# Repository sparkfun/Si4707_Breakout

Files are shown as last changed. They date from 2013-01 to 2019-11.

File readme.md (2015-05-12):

SparkFun Si4707 Weather Band Radio Receiver
==================================

SparkFun Si4707 Weather Band Radio Breakout  

[*SparkFun Si4707 Weather Band Radio Breakout (WRL-11129)*](https://www.sparkfun.com/products/11129)

The Si4707 IC is the industry's first weather band (WB) radio receiver to include a specific area message encoding (SAME) processor. 

Features:

* Weather band support (162.4–162.55 MHz)
* SAME processor
* 1050 Hz alert tone detection
* Frequency synthesizer with integrated VCO
* WB digital tuning
* Programmable reference clock
* 2.7 to 5.5 V supply voltage

Repository Contents
-------------------
* **/Firmware** - Arduino example sketch
* **/Hardware** - PCB design files (created with version 6.2.0 of Eagle)
* **/Production** - Production panel files (.brd)
* [Wiki](https://github.com/sparkfun/Si4707_Breakout/wiki) - Be sure to check out the [hardware support](https://github.com/sparkfun/Si4707_Breakout/wiki/Si4707-Breakout-Hardware-Support) page for more information on using the Si4707 breakout board.

Documentation
--------------
* **[Hookup Guide](https://learn.sparkfun.com/tutorials/si4707-hookup-guide)** - Basic hookup guide for the sI4707.
* **[SparkFun Fritzing repo](https://github.com/sparkfun/Fritzing_Parts)** - Fritzing diagrams for SparkFun products.
* **[SparkFun 3D Model repo](https://github.com/sparkfun/3D_Models)** - 3D models of SparkFun products. 

License Information
-------------------
This product is _**open source**_! 

The **hardware** is released under [Creative Commons ShareAlike 4.0 International](https://creativecommons.org/licenses/by-sa/4.0/).

The **code** is beerware; if you see me (or any other SparkFun employee) at the local, and you've found our code helpful, please buy us a round!

Please use, reuse, and modify these files as you see fit. Please maintain attribution to SparkFun Electronics and release anything derivative under the same license.

Distributed as-is; no warranty is given.

- Your friends at SparkFun.

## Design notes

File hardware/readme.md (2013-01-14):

# What Are these Files?

The .sch and .brd files hare are Eagle CAD schematic and PCB design files.

These files were created with Eagle 6.2.0, you'll need Eagle 6.0 or later to open them up. There is a free, lite, version of Eagle available from [cadsoftusa.com](cadsoftusa.com).

# Board Features

# License

This product is open source! These Eagle files are released under the Creative Commons Share-Alike Attribution license ([CC BY-SA 3.0](http://creativecommons.org/licenses/by-sa/3.0/us/)).

Please use, reuse, and modify these files as you see fit. Please maintain attribution and release anything derivative under the same license.

- Your friends at SparkFun.

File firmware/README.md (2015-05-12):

SparkFun Si4707 Weather Band Radio Firmware
============================================

* **Si4707_Example_Code_I2C** - Arduino Example sketches

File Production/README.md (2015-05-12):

SparkFun <PRODUCT NAME> Production Files
=========================================

These are the production files SparkFun uses for printing PCBs.

License Information
-------------------
This product is open source! 

The hardware is released under [Creative Commons ShareAlike 4.0 International](https://creativecommons.org/licenses/by-sa/4.0/).

Please use, reuse, and modify these files as you see fit. Please maintain attribution to SparkFun Electronics and release anything derivative under the same license.

Distributed as-is; no warranty is given.

- Your friends at SparkFun.

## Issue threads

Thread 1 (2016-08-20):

No need to wait for data after Wire.requestFrom() and no endTransmission.

Koepel, 2016-08-20:
In the file si4707_system_functions.ino, there is no need for a timeout after the Wire.requestFrom() call. And it should not be followed by a Wire.endTransmission.

When the Wire.requestFrom() function returns, the I2C transaction has completely finished and the received data is in the receive buffer in the Wire library. The Wire.read() only reads data from that buffer.

loricrotser, 2019-11-05:
Verified and Fixed.

Koepel, 2019-11-05:
There is still a timeout after the Wire.requestFrom() in the code. The timeout can be removed.
Explanation: [Common-mistakes#1](https://github.com/Koepel/How-to-use-the-Arduino-Wire-library/wiki/Common-mistakes#1)

When the sensor is not connected (or when there was a bus error), the Wire.available() returns zero. In that case, the timeout will eventually become zero and the data is not read.
However, there is no need for a timeout and a single check is enough to test if the sensor is not connected (or if there was a bus error):
```
void i2cReadBytes(byte number_bytes, byte * data_in)
{
  Wire.requestFrom((byte) SI4707_ADDRESS, number_bytes);
  if(Wire.available() == number_bytes)
  {
    while(number_bytes--)
    {
      *data_in++ = Wire.read();
    }
  }
}
```

Closed 2019-11-05.

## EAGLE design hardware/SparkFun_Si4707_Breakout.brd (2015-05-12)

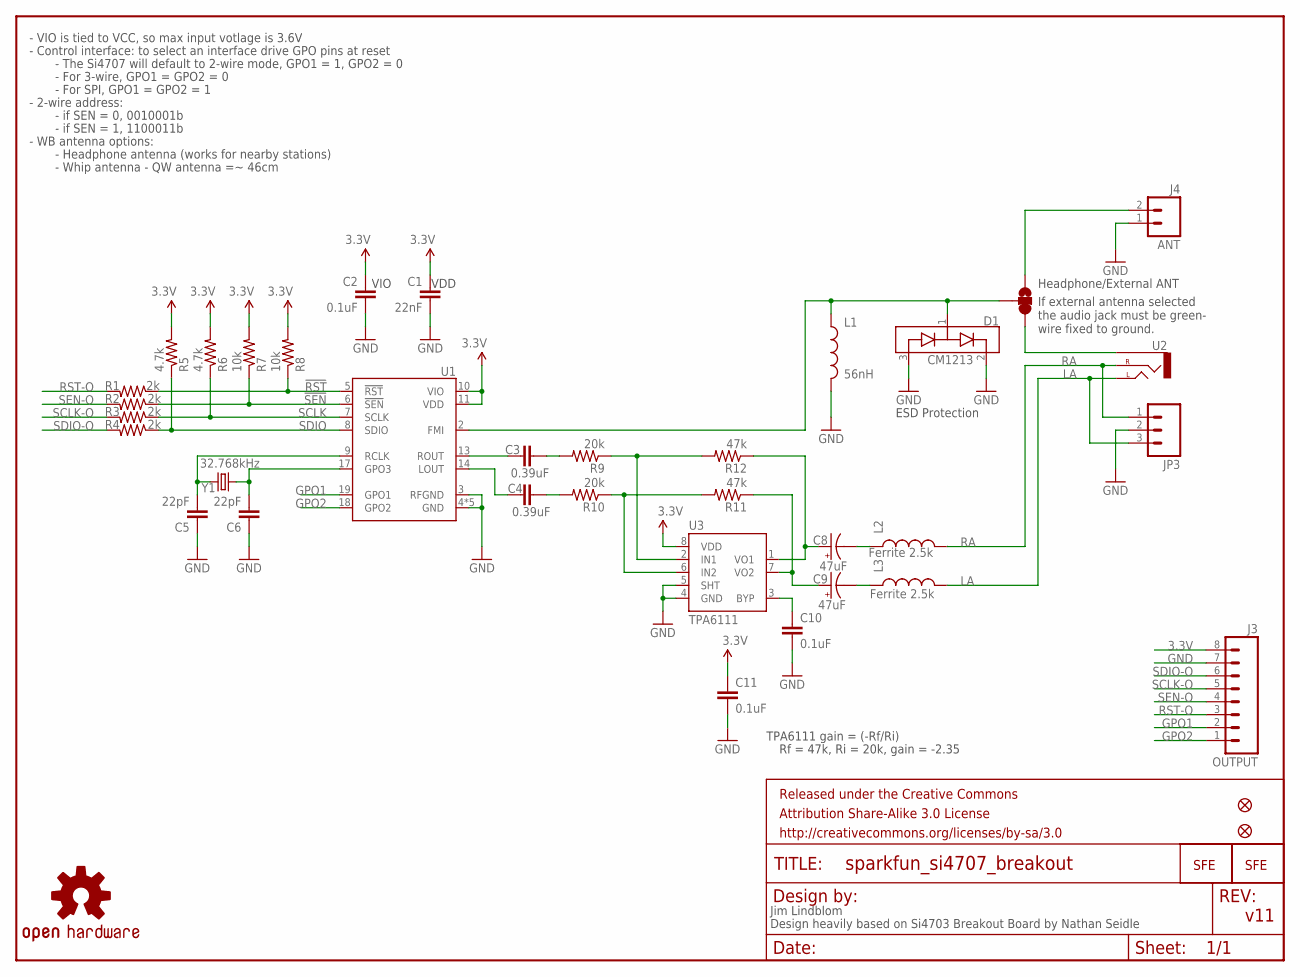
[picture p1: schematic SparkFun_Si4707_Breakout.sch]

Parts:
C1: 22nF; 0402-CAP
C2, C10, C11: 0.1uF; 0402-CAP
C3, C4: 0.39uF; 0402-CAP
C5, C6: 22pF; 0402-CAP
C8, C9: 47uF; EIA3528
D1: CM1213; SOT23-3
FRAME1: FRAME-LETTER; CREATIVE_COMMONS
J3: OUTPUT; 1X08
J4: ANT; 1X02
JP1: LOGO-SFENEW; SFE-NEW-WEBLOGO
JP2: LOGO-SFESK; SFE-LOGO-FLAME
JP3: M03PTH; 1X03
JP4, JP5: FIDUCIALUFIDUCIAL; MICRO-FIDUCIAL
L1: 56nH; 0603
L2, L3: Ferrite 2.5k; C0402
R1, R2, R3, R4: 2k; 0402-RES
R5, R6: 4.7k; 0402-RES
R7, R8: 10k; 0402-RES
R9, R10: 20k; 0402-RES
R11, R12: 47k; 0402-RES
SJ2: SOLDERJUMPER_2WAYS; SJ_3
U1: SI4707; SI470X
U2: AUDIO-JACKSMD2; AUDIO-JACK-3.5MM-SMD
U3: TPA6111; SPARKFUN_SO08
U$2: OSHW-LOGOS; OSHW-LOGO-S
Y1: 32.768kHz; CRYSTAL-32KHZ-SMD

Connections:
3.3V: C1.1, C2.1, C11.1, J3.8, R5.2, R6.2, R7.2, R8.2, U1.10 (VIO), U1.11 (VDD), U3.8 (VDD)
!RST: R1.1, R8.1, U1.5 (!RST)
!SEN: R2.1, R7.1, U1.6 (!SEN)
GND: C1.2, C2.2, C5.1, C6.1, C10.2, C11.2, D1.2 (VP), D1.3 (VN), J3.7, J4.1, JP3.2, L1.2, U1.3 (RFGND), U1.4 (GND), U1.12 (GND), U1.15 (GND), U1.16 (GND), U1.21 (GND), U3.4 (GND), U3.5 (SHT)
GPO1: J3.2, U1.19 (GPO1)
GPO2: J3.1, U1.18 (GPO2)
J1: D1.1 (CH1), L1.1, SJ2.2, U1.2 (FMI)
LA: JP3.3, L3.2, U2.TIP (LEFT)
LOUT: C4.1, U1.14 (LOUT)
unnamed: C3.2, R9.2
unnamed: C4.2, R10.2
unnamed: C6.2, U1.17 (GPO3), Y1.X1 (1)
unnamed: SJ2.1, U2.SLEEVE
unnamed: J4.2, SJ2.3
unnamed: R9.1, R12.2, U3.2 (IN1)
unnamed: R10.1, R11.2, U3.6 (IN2)
unnamed: C10.1, U3.3 (BYP)
unnamed: C8.C (-), L2.1
unnamed: C9.C (-), L3.1
unnamed: C8.A (+), R12.1, U3.1 (VO1)
unnamed: C9.A (+), R11.1, U3.7 (VO2)
RA: JP3.1, L2.2, U2.RING (RIGHT)
RCLK: C5.2, U1.9 (RCLK), Y1.X2 (2)
ROUT: C3.1, U1.13 (ROUT)
RST-O: J3.3, R1.2
SCLK: R3.1, R6.1, U1.7 (SCLK)
SCLK-O: J3.5, R3.2
SDIO: R4.1, R5.1, U1.8 (SDIO)
SDIO-O: J3.6, R4.2
SEN-O: J3.4, R2.2

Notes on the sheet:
Jim Lindblom
VDD
VIO
Design heavily based on Si4703 Breakout Board by Nathan Seidle
- VIO is tied to VCC, so max input votlage is 3.6V
- Control interface: to select an interface drive GPO pins at reset
- The Si4707 will default to 2-wire mode, GPO1 = 1, GPO2 = 0
- For 3-wire, GPO1 = GPO2 = 0
- For SPI, GPO1 = GPO2 = 1
- 2-wire address:
- if SEN = 0, 0010001b
- if SEN = 1, 1100011b
- WB antenna options:
- Headphone antenna (works for nearby stations)
- Whip antenna - QW antenna =~ 46cm
ESD Protection
Headphone/External ANT
TPA6111 gain = (-Rf/Ri)
Rf = 47k, Ri = 20k, gain = -2.35
If external antenna selected the audio jack must be green- wire fixed to ground.
v11

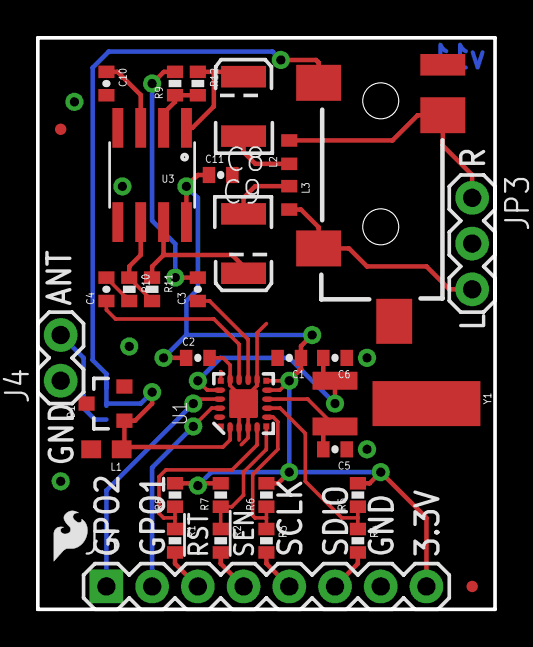
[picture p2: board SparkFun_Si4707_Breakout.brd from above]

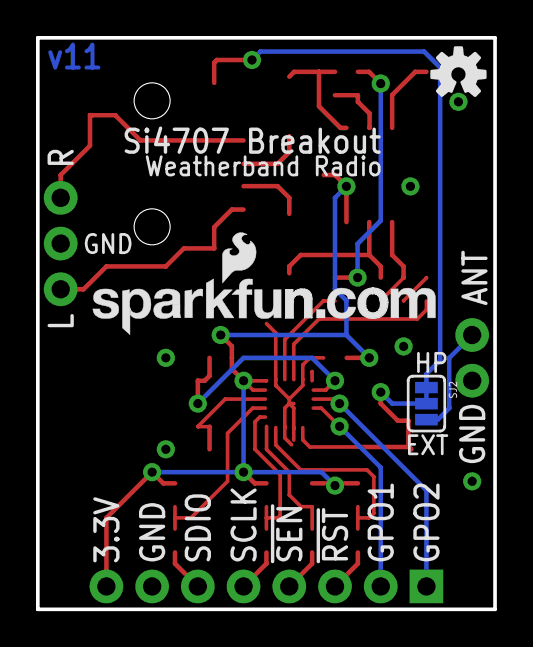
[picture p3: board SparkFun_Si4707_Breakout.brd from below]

Board: 2 copper layers, 25.4 x 31.8 mm, 40 parts (3 on the bottom side), 30 nets.

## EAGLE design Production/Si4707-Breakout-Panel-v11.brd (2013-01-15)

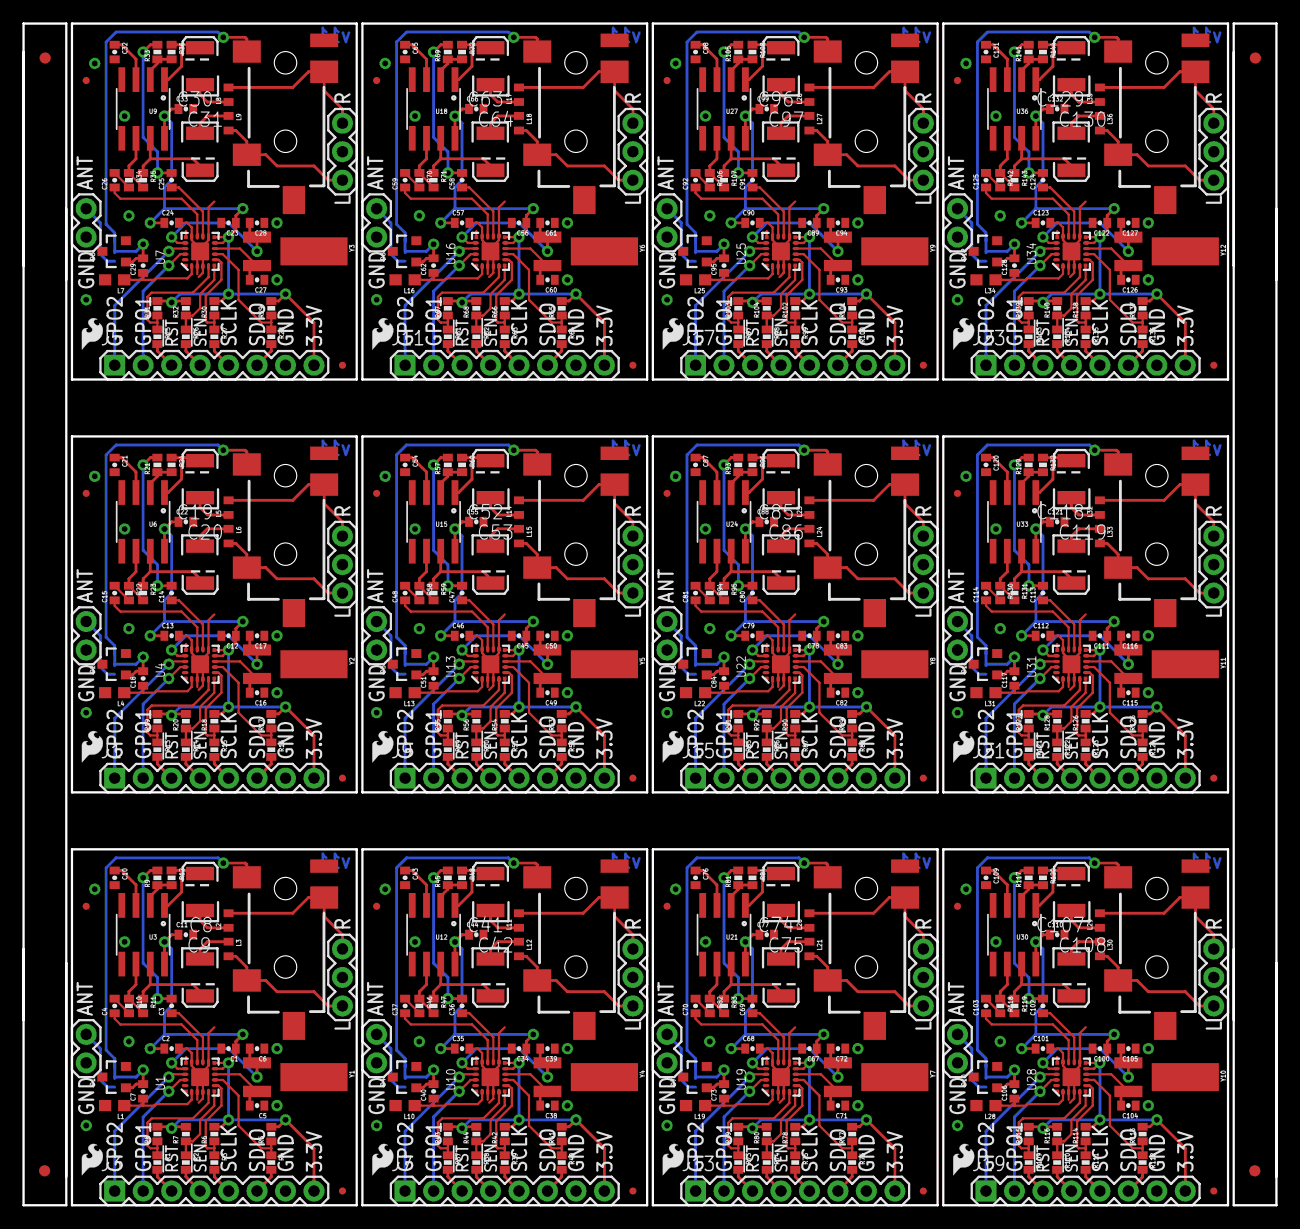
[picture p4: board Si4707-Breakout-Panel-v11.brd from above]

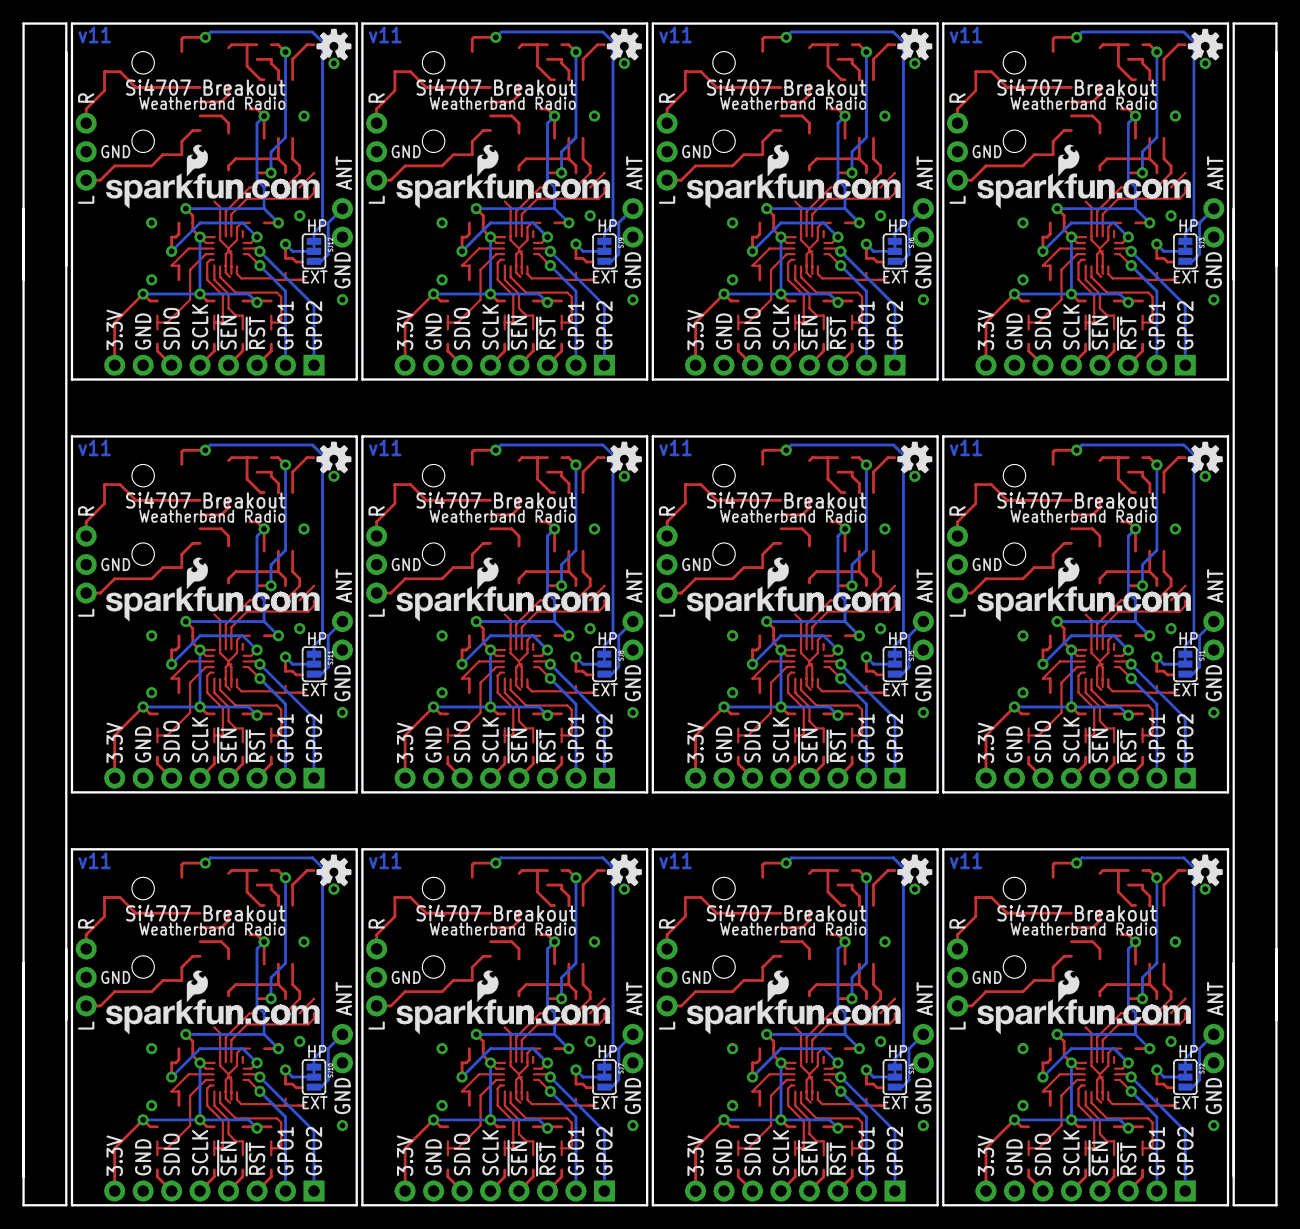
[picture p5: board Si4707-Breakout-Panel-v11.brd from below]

Board: 2 copper layers, 111.8 x 105.4 mm, 484 parts (36 on the bottom side), 372 nets.

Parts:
C1, C12, C23, C34, C45, C56, C67, C78, C89, C100, C111, C122: 22nF; 0402-CAP
C2, C10, C11, C13, C21, C22, C24, C32, C33, C35, C43, C44, C46, C54, C55, C57, C65, C66, C68, C76, C77, C79, C87, C88, C90, C98, C99, C101, C109, C110, C112, C120, C121, C123, C131, C132: 0.1uF; 0402-CAP
C3, C4, C14, C15, C25, C26, C36, C37, C47, C48, C58, C59, C69, C70, C80, C81, C91, C92, C102, C103, C113, C114, C124, C125: 0.39uF; 0402-CAP
C5, C6, C16, C17, C27, C28, C38, C39, C49, C50, C60, C61, C71, C72, C82, C83, C93, C94, C104, C105, C115, C116, C126, C127: 22pF; 0402-CAP
C7, C18, C29, C40, C51, C62, C73, C84, C95, C106, C117, C128: 1nF; 0402-CAP
C8, C9, C19, C20, C30, C31, C41, C42, C52, C53, C63, C64, C74, C75, C85, C86, C96, C97, C107, C108, C118, C119, C129, C130: 47uF; EIA3528
D1, D2, D3, D4, D5, D6, D7, D8, D9, D10, D11, D12: CM1213; SOT23-3
E$1, E$2, E$3, E$4: FIDUCIAL-1X2
J1, J3, J5, J7, J9, J11, J13, J15, J17, J19, J21, J23: OUTPUT; 1X08
J2, J4, J6, J8, J10, J12, J14, J16, J18, J20, J22, J24: ANT; 1X02
JP1, JP6, JP11, JP16, JP21, JP26, JP31, JP36, JP41, JP46, JP51, JP56: LOGO-SFENEW; SFE-NEW-WEBLOGO
JP2, JP7, JP12, JP17, JP22, JP27, JP32, JP37, JP42, JP47, JP52, JP57: LOGO-SFESK; SFE-LOGO-FLAME
JP3, JP8, JP13, JP18, JP23, JP28, JP33, JP38, JP43, JP48, JP53, JP58: 1X03
JP4, JP5, JP9, JP10, JP14, JP15, JP19, JP20, JP24, JP25, JP29, JP30, JP34, JP35, JP39, JP40, JP44, JP45, JP49, JP50, JP54, JP55, JP59, JP60: FIDUCIALUFIDUCIAL; MICRO-FIDUCIAL
L1, L4, L7, L10, L13, L16, L19, L22, L25, L28, L31, L34: 56nH; 0603
L2, L3, L5, L6, L8, L9, L11, L12, L14, L15, L17, L18, L20, L21, L23, L24, L26, L27, L29, L30, L32, L33, L35, L36: Ferrite 2.5k; C0402
R1, R2, R3, R4, R13, R14, R15, R16, R25, R26, R27, R28, R37, R38, R39, R40, R49, R50, R51, R52, R61, R62, R63, R64, R73, R74, R75, R76, R85, R86, R87, R88, R97, R98, R99, R100, R109, R110, R111, R112, R121, R122, R123, R124, R133, R134, R135, R136: 2k; 0402-RES
R5, R6, R17, R18, R29, R30, R41, R42, R53, R54, R65, R66, R77, R78, R89, R90, R101, R102, R113, R114, R125, R126, R137, R138: 4.7k; 0402-RES
R7, R8, R19, R20, R31, R32, R43, R44, R55, R56, R67, R68, R79, R80, R91, R92, R103, R104, R115, R116, R127, R128, R139, R140: 10k; 0402-RES
R9, R10, R21, R22, R33, R34, R45, R46, R57, R58, R69, R70, R81, R82, R93, R94, R105, R106, R117, R118, R129, R130, R141, R142: 20k; 0402-RES
R11, R12, R23, R24, R35, R36, R47, R48, R59, R60, R71, R72, R83, R84, R95, R96, R107, R108, R119, R120, R131, R132, R143, R144: 47k; 0402-RES
SJ1, SJ2, SJ3, SJ4, SJ5, SJ6, SJ7, SJ8, SJ9, SJ10, SJ11, SJ12: SJ_3
U1, U4, U7, U10, U13, U16, U19, U22, U25, U28, U31, U34: SI470X
U2, U5, U8, U11, U14, U17, U20, U23, U26, U29, U32, U35: AUDIO-JACK-3.5MM-SMD
U3, U6, U9, U12, U15, U18, U21, U24, U27, U30, U33, U36: TPA6111; SPARKFUN_SO08
U$1, U$2, U$3, U$4, U$5, U$6, U$7, U$8, U$9, U$10, U$11, U$12: OSHW-LOGOS; OSHW-LOGO-S
Y1, Y2, Y3, Y4, Y5, Y6, Y7, Y8, Y9, Y10, Y11, Y12: 32.768kHz; CRYSTAL-32KHZ-SMD

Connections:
3.3V: C1.1, C2.1, C11.1, J3.8, R5.2, R6.2, R7.2, R8.2, U1.10, U1.11, U3.8
3.3V1: C12.1, C13.1, C22.1, J1.8, R17.2, R18.2, R19.2, R20.2, U4.10, U4.11, U6.8
3.3V2: C23.1, C24.1, C33.1, J5.8, R29.2, R30.2, R31.2, R32.2, U7.10, U7.11, U9.8
3.3V3: C34.1, C35.1, C44.1, J7.8, R41.2, R42.2, R43.2, R44.2, U10.10, U10.11, U12.8
3.3V4: C45.1, C46.1, C55.1, J9.8, R53.2, R54.2, R55.2, R56.2, U13.10, U13.11, U15.8
3.3V5: C56.1, C57.1, C66.1, J11.8, R65.2, R66.2, R67.2, R68.2, U16.10, U16.11, U18.8
3.3V6: C67.1, C68.1, C77.1, J13.8, R77.2, R78.2, R79.2, R80.2, U19.10, U19.11, U21.8
3.3V7: C78.1, C79.1, C88.1, J15.8, R89.2, R90.2, R91.2, R92.2, U22.10, U22.11, U24.8
3.3V8: C89.1, C90.1, C99.1, J17.8, R101.2, R102.2, R103.2, R104.2, U25.10, U25.11, U27.8
3.3V9: C100.1, C101.1, C110.1, J19.8, R113.2, R114.2, R115.2, R116.2, U28.10, U28.11, U30.8
3.3V10: C111.1, C112.1, C121.1, J21.8, R125.2, R126.2, R127.2, R128.2, U31.10, U31.11, U33.8
3.3V11: C122.1, C123.1, C132.1, J23.8, R137.2, R138.2, R139.2, R140.2, U34.10, U34.11, U36.8
!RST: R1.1, R8.1, U1.5
!RST1: R13.1, R19.1, U4.5
!RST2: R25.1, R31.1, U7.5
!RST3: R37.1, R43.1, U10.5
!RST4: R49.1, R55.1, U13.5
!RST5: R61.1, R67.1, U16.5
!RST6: R73.1, R79.1, U19.5
!RST7: R85.1, R91.1, U22.5
!RST8: R97.1, R103.1, U25.5
!RST9: R109.1, R115.1, U28.5
!RST10: R121.1, R127.1, U31.5
!RST11: R133.1, R139.1, U34.5
!SEN: R2.1, R7.1, U1.6
!SEN1: R14.1, R20.1, U4.6
!SEN2: R26.1, R32.1, U7.6
!SEN3: R38.1, R44.1, U10.6
!SEN4: R50.1, R56.1, U13.6
!SEN5: R62.1, R68.1, U16.6
!SEN6: R74.1, R80.1, U19.6
!SEN7: R86.1, R92.1, U22.6
!SEN8: R98.1, R104.1, U25.6
!SEN9: R110.1, R116.1, U28.6
!SEN10: R122.1, R128.1, U31.6
!SEN11: R134.1, R140.1, U34.6
GND: C1.2, C2.2, C5.1, C6.1, C10.2, C11.2, D1.2, D1.3, J3.7, J4.1, JP3.2, L1.2, U1.3, U1.4, U1.12, U1.15, U1.16, U1.21, U3.4, U3.5
GND1: C12.2, C13.2, C16.1, C17.1, C21.2, C22.2, D2.2, D2.3, J1.7, J2.1, JP8.2, L4.2, U4.3, U4.4, U4.12, U4.15, U4.16, U4.21, U6.4, U6.5
GND2: C23.2, C24.2, C27.1, C28.1, C32.2, C33.2, D3.2, D3.3, J5.7, J6.1, JP13.2, L7.2, U7.3, U7.4, U7.12, U7.15, U7.16, U7.21, U9.4, U9.5
GND3: C34.2, C35.2, C38.1, C39.1, C43.2, C44.2, D4.2, D4.3, J7.7, J8.1, JP18.2, L10.2, U10.3, U10.4, U10.12, U10.15, U10.16, U10.21, U12.4, U12.5
GND4: C45.2, C46.2, C49.1, C50.1, C54.2, C55.2, D5.2, D5.3, J9.7, J10.1, JP23.2, L13.2, U13.3, U13.4, U13.12, U13.15, U13.16, U13.21, U15.4, U15.5
GND5: C56.2, C57.2, C60.1, C61.1, C65.2, C66.2, D6.2, D6.3, J11.7, J12.1, JP28.2, L16.2, U16.3, U16.4, U16.12, U16.15, U16.16, U16.21, U18.4, U18.5
GND6: C67.2, C68.2, C71.1, C72.1, C76.2, C77.2, D7.2, D7.3, J13.7, J14.1, JP33.2, L19.2, U19.3, U19.4, U19.12, U19.15, U19.16, U19.21, U21.4, U21.5
GND7: C78.2, C79.2, C82.1, C83.1, C87.2, C88.2, D8.2, D8.3, J15.7, J16.1, JP38.2, L22.2, U22.3, U22.4, U22.12, U22.15, U22.16, U22.21, U24.4, U24.5
GND8: C89.2, C90.2, C93.1, C94.1, C98.2, C99.2, D9.2, D9.3, J17.7, J18.1, JP43.2, L25.2, U25.3, U25.4, U25.12, U25.15, U25.16, U25.21, U27.4, U27.5
GND9: C100.2, C101.2, C104.1, C105.1, C109.2, C110.2, D10.2, D10.3, J19.7, J20.1, JP48.2, L28.2, U28.3, U28.4, U28.12, U28.15, U28.16, U28.21, U30.4, U30.5
GND10: C111.2, C112.2, C115.1, C116.1, C120.2, C121.2, D11.2, D11.3, J21.7, J22.1, JP53.2, L31.2, U31.3, U31.4, U31.12, U31.15, U31.16, U31.21, U33.4, U33.5
GND11: C122.2, C123.2, C126.1, C127.1, C131.2, C132.2, D12.2, D12.3, J23.7, J24.1, JP58.2, L34.2, U34.3, U34.4, U34.12, U34.15, U34.16, U34.21, U36.4, U36.5
GPO1: J3.2, U1.19
GPO2: J3.1, U1.18
GPO3: J1.2, U4.19
GPO4: J1.1, U4.18
GPO5: J5.2, U7.19
GPO6: J5.1, U7.18
GPO7: J7.2, U10.19
GPO8: J7.1, U10.18
GPO9: J9.2, U13.19
GPO10: J9.1, U13.18
GPO11: J11.2, U16.19
GPO12: J11.1, U16.18
GPO13: J13.2, U19.19
GPO14: J13.1, U19.18
GPO15: J15.2, U22.19
GPO16: J15.1, U22.18
GPO17: J17.2, U25.19
GPO18: J17.1, U25.18
GPO19: J19.2, U28.19
GPO20: J19.1, U28.18
GPO21: J21.2, U31.19
GPO22: J21.1, U31.18
GPO23: J23.2, U34.19
GPO24: J23.1, U34.18
J1: C7.2, D1.1, SJ2.2
J2: C18.2, D2.1, SJ1.2
J3: C29.2, D3.1, SJ3.2
J4: C40.2, D4.1, SJ4.2
J5: C51.2, D5.1, SJ5.2
J6: C62.2, D6.1, SJ6.2
J7: C73.2, D7.1, SJ7.2
J8: C84.2, D8.1, SJ8.2
J9: C95.2, D9.1, SJ9.2
J10: C106.2, D10.1, SJ10.2
J11: C117.2, D11.1, SJ11.2
J12: C128.2, D12.1, SJ12.2
LA: JP3.3, L3.2, U2.TIP
LA1: JP8.3, L6.2, U5.TIP
LA2: JP13.3, L9.2, U8.TIP
LA3: JP18.3, L12.2, U11.TIP
LA4: JP23.3, L15.2, U14.TIP
LA5: JP28.3, L18.2, U17.TIP
LA6: JP33.3, L21.2, U20.TIP
LA7: JP38.3, L24.2, U23.TIP
LA8: JP43.3, L27.2, U26.TIP
LA9: JP48.3, L30.2, U29.TIP
LA10: JP53.3, L33.2, U32.TIP
LA11: JP58.3, L36.2, U35.TIP
LOUT: C4.1, U1.14
LOUT1: C15.1, U4.14
LOUT2: C26.1, U7.14
LOUT3: C37.1, U10.14
LOUT4: C48.1, U13.14
LOUT5: C59.1, U16.14
LOUT6: C70.1, U19.14
LOUT7: C81.1, U22.14
LOUT8: C92.1, U25.14
LOUT9: C103.1, U28.14
LOUT10: C114.1, U31.14
LOUT11: C125.1, U34.14
unnamed: C14.2, R21.2
unnamed: C3.2, R9.2
unnamed: C4.2, R10.2
unnamed: C15.2, R22.2
unnamed: C6.2, U1.17, Y1.X1
unnamed: SJ2.1, U2.SLEEVE
unnamed: C7.1, L1.1, U1.2
unnamed: J4.2, SJ2.3
unnamed: R9.1, R12.2, U3.2
unnamed: R10.1, R11.2, U3.6
unnamed: C10.1, U3.3
unnamed: C8.C, L2.1
unnamed: C9.C, L3.1
unnamed: C8.A, R12.1, U3.1
unnamed: C9.A, R11.1, U3.7
unnamed: C17.2, U4.17, Y2.X1
unnamed: C18.1, L4.1, U4.2
unnamed: SJ1.1, U5.SLEEVE
unnamed: J2.2, SJ1.3
unnamed: R21.1, R24.2, U6.2
unnamed: R22.1, R23.2, U6.6
unnamed: C21.1, U6.3
unnamed: C19.C, L5.1
unnamed: C20.C, L6.1
unnamed: C19.A, R24.1, U6.1
unnamed: C20.A, R23.1, U6.7
unnamed: C25.2, R33.2
unnamed: C26.2, R34.2
unnamed: C28.2, U7.17, Y3.X1
unnamed: C29.1, L7.1, U7.2
unnamed: SJ3.1, U8.SLEEVE
unnamed: J6.2, SJ3.3
unnamed: R33.1, R36.2, U9.2
unnamed: R34.1, R35.2, U9.6
unnamed: C32.1, U9.3
unnamed: C30.C, L8.1
unnamed: C31.C, L9.1
unnamed: C30.A, R36.1, U9.1
unnamed: C31.A, R35.1, U9.7
unnamed: C36.2, R45.2
unnamed: C37.2, R46.2
unnamed: C39.2, U10.17, Y4.X1
unnamed: C40.1, L10.1, U10.2
unnamed: SJ4.1, U11.SLEEVE
unnamed: J8.2, SJ4.3
unnamed: R45.1, R48.2, U12.2
unnamed: R46.1, R47.2, U12.6
unnamed: C43.1, U12.3
unnamed: C41.C, L11.1
unnamed: C42.C, L12.1
unnamed: C41.A, R48.1, U12.1
unnamed: C42.A, R47.1, U12.7
unnamed: C47.2, R57.2
unnamed: C48.2, R58.2
unnamed: C50.2, U13.17, Y5.X1
unnamed: C51.1, L13.1, U13.2
unnamed: SJ5.1, U14.SLEEVE
unnamed: J10.2, SJ5.3
unnamed: R57.1, R60.2, U15.2
unnamed: R58.1, R59.2, U15.6
unnamed: C54.1, U15.3
unnamed: C52.C, L14.1
unnamed: C53.C, L15.1
unnamed: C52.A, R60.1, U15.1
unnamed: C53.A, R59.1, U15.7
unnamed: C58.2, R69.2
unnamed: C59.2, R70.2
unnamed: C61.2, U16.17, Y6.X1
unnamed: C62.1, L16.1, U16.2
unnamed: SJ6.1, U17.SLEEVE
unnamed: J12.2, SJ6.3
unnamed: R69.1, R72.2, U18.2
unnamed: R70.1, R71.2, U18.6
unnamed: C65.1, U18.3
unnamed: C63.C, L17.1
unnamed: C64.C, L18.1
unnamed: C63.A, R72.1, U18.1
unnamed: C64.A, R71.1, U18.7
unnamed: C69.2, R81.2
unnamed: C70.2, R82.2
unnamed: C72.2, U19.17, Y7.X1
unnamed: C73.1, L19.1, U19.2
unnamed: SJ7.1, U20.SLEEVE
unnamed: J14.2, SJ7.3
unnamed: R81.1, R84.2, U21.2
unnamed: R82.1, R83.2, U21.6
unnamed: C76.1, U21.3
unnamed: C74.C, L20.1
unnamed: C75.C, L21.1
unnamed: C74.A, R84.1, U21.1
unnamed: C75.A, R83.1, U21.7
unnamed: C80.2, R93.2
unnamed: C81.2, R94.2
unnamed: C83.2, U22.17, Y8.X1
unnamed: C84.1, L22.1, U22.2
unnamed: SJ8.1, U23.SLEEVE
unnamed: J16.2, SJ8.3
unnamed: R93.1, R96.2, U24.2
unnamed: R94.1, R95.2, U24.6
unnamed: C87.1, U24.3
unnamed: C85.C, L23.1
unnamed: C86.C, L24.1
unnamed: C85.A, R96.1, U24.1
unnamed: C86.A, R95.1, U24.7
unnamed: C91.2, R105.2
unnamed: C92.2, R106.2
unnamed: C94.2, U25.17, Y9.X1
unnamed: C95.1, L25.1, U25.2
unnamed: SJ9.1, U26.SLEEVE
unnamed: J18.2, SJ9.3
unnamed: R105.1, R108.2, U27.2
unnamed: R106.1, R107.2, U27.6
unnamed: C98.1, U27.3
unnamed: C96.C, L26.1
unnamed: C97.C, L27.1
unnamed: C96.A, R108.1, U27.1
unnamed: C97.A, R107.1, U27.7
unnamed: C102.2, R117.2
unnamed: C103.2, R118.2
unnamed: C105.2, U28.17, Y10.X1
unnamed: C106.1, L28.1, U28.2
unnamed: SJ10.1, U29.SLEEVE
unnamed: J20.2, SJ10.3
unnamed: R117.1, R120.2, U30.2
unnamed: R118.1, R119.2, U30.6
unnamed: C109.1, U30.3
unnamed: C107.C, L29.1
unnamed: C108.C, L30.1
unnamed: C107.A, R120.1, U30.1
unnamed: C108.A, R119.1, U30.7
unnamed: C113.2, R129.2
unnamed: C114.2, R130.2
unnamed: C116.2, U31.17, Y11.X1
unnamed: C117.1, L31.1, U31.2
unnamed: SJ11.1, U32.SLEEVE
unnamed: J22.2, SJ11.3
unnamed: R129.1, R132.2, U33.2
unnamed: R130.1, R131.2, U33.6
unnamed: C120.1, U33.3
unnamed: C118.C, L32.1
unnamed: C119.C, L33.1
unnamed: C118.A, R132.1, U33.1
unnamed: C119.A, R131.1, U33.7
unnamed: C124.2, R141.2
unnamed: C125.2, R142.2
unnamed: C127.2, U34.17, Y12.X1
unnamed: C128.1, L34.1, U34.2
unnamed: SJ12.1, U35.SLEEVE
unnamed: J24.2, SJ12.3
unnamed: R141.1, R144.2, U36.2
unnamed: R142.1, R143.2, U36.6
unnamed: C131.1, U36.3
unnamed: C129.C, L35.1
unnamed: C130.C, L36.1
unnamed: C129.A, R144.1, U36.1
unnamed: C130.A, R143.1, U36.7
RA: JP3.1, L2.2, U2.RING
RA1: JP8.1, L5.2, U5.RING
RA2: JP13.1, L8.2, U8.RING
RA3: JP18.1, L11.2, U11.RING
RA4: JP23.1, L14.2, U14.RING
RA5: JP28.1, L17.2, U17.RING
RA6: JP33.1, L20.2, U20.RING
RA7: JP38.1, L23.2, U23.RING
RA8: JP43.1, L26.2, U26.RING
RA9: JP48.1, L29.2, U29.RING
RA10: JP53.1, L32.2, U32.RING
RA11: JP58.1, L35.2, U35.RING
RCLK: C5.2, U1.9, Y1.X2
RCLK1: C16.2, U4.9, Y2.X2
RCLK2: C27.2, U7.9, Y3.X2
RCLK3: C38.2, U10.9, Y4.X2
RCLK4: C49.2, U13.9, Y5.X2
RCLK5: C60.2, U16.9, Y6.X2
RCLK6: C71.2, U19.9, Y7.X2
RCLK7: C82.2, U22.9, Y8.X2
RCLK8: C93.2, U25.9, Y9.X2
RCLK9: C104.2, U28.9, Y10.X2
RCLK10: C115.2, U31.9, Y11.X2
RCLK11: C126.2, U34.9, Y12.X2
ROUT: C3.1, U1.13
ROUT1: C14.1, U4.13
ROUT2: C25.1, U7.13
ROUT3: C36.1, U10.13
ROUT4: C47.1, U13.13
ROUT5: C58.1, U16.13
ROUT6: C69.1, U19.13
ROUT7: C80.1, U22.13
ROUT8: C91.1, U25.13
ROUT9: C102.1, U28.13
ROUT10: C113.1, U31.13
ROUT11: C124.1, U34.13
RST-O: J3.3, R1.2
RST-O1: J1.3, R13.2
RST-O2: J5.3, R25.2
RST-O3: J7.3, R37.2
RST-O4: J9.3, R49.2
RST-O5: J11.3, R61.2
RST-O6: J13.3, R73.2
RST-O7: J15.3, R85.2
RST-O8: J17.3, R97.2
RST-O9: J19.3, R109.2
RST-O10: J21.3, R121.2
RST-O11: J23.3, R133.2
SCLK: R3.1, R6.1, U1.7
SCLK1: R15.1, R18.1, U4.7
SCLK2: R27.1, R30.1, U7.7
SCLK3: R39.1, R42.1, U10.7
SCLK4: R51.1, R54.1, U13.7
SCLK5: R63.1, R66.1, U16.7
SCLK6: R75.1, R78.1, U19.7
SCLK7: R87.1, R90.1, U22.7
SCLK8: R99.1, R102.1, U25.7
SCLK9: R111.1, R114.1, U28.7
SCLK10: R123.1, R126.1, U31.7
SCLK11: R135.1, R138.1, U34.7
SCLK-O: J3.5, R3.2
SCLK-O1: J1.5, R15.2
SCLK-O2: J5.5, R27.2
SCLK-O3: J7.5, R39.2
SCLK-O4: J9.5, R51.2
SCLK-O5: J11.5, R63.2
SCLK-O6: J13.5, R75.2
SCLK-O7: J15.5, R87.2
SCLK-O8: J17.5, R99.2
SCLK-O9: J19.5, R111.2
SCLK-O10: J21.5, R123.2
SCLK-O11: J23.5, R135.2
SDIO: R4.1, R5.1, U1.8
SDIO1: R16.1, R17.1, U4.8
SDIO2: R28.1, R29.1, U7.8
SDIO3: R40.1, R41.1, U10.8
SDIO4: R52.1, R53.1, U13.8
SDIO5: R64.1, R65.1, U16.8
SDIO6: R76.1, R77.1, U19.8
SDIO7: R88.1, R89.1, U22.8
SDIO8: R100.1, R101.1, U25.8
SDIO9: R112.1, R113.1, U28.8
SDIO10: R124.1, R125.1, U31.8
SDIO11: R136.1, R137.1, U34.8
SDIO-O: J3.6, R4.2
SDIO-O1: J1.6, R16.2
SDIO-O2: J5.6, R28.2
SDIO-O3: J7.6, R40.2
SDIO-O4: J9.6, R52.2
SDIO-O5: J11.6, R64.2
SDIO-O6: J13.6, R76.2
SDIO-O7: J15.6, R88.2
SDIO-O8: J17.6, R100.2
SDIO-O9: J19.6, R112.2
SDIO-O10: J21.6, R124.2
SDIO-O11: J23.6, R136.2
SEN-O: J3.4, R2.2
SEN-O1: J1.4, R14.2
SEN-O2: J5.4, R26.2
SEN-O3: J7.4, R38.2
SEN-O4: J9.4, R50.2
SEN-O5: J11.4, R62.2
SEN-O6: J13.4, R74.2
SEN-O7: J15.4, R86.2
SEN-O8: J17.4, R98.2
SEN-O9: J19.4, R110.2
SEN-O10: J21.4, R122.2
SEN-O11: J23.4, R134.2

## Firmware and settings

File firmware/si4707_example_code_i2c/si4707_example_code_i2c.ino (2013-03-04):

/* Si4707 Breakout Example Code - I2C version
  by: Jim Lindblom
      SparkFun Electronics
  date: February 28, 2012
  
  license: Beerware. Please use, re-use, and modify this code without 
  restriction! We hope you find it useful. If you do, feel free to buy us
  a beer when we meet :).
  
  This example code shows off some of the functionality of the Si4707
  weather band receiver IC. Throw this code on your favorite Arduino
  and connect it like so:
  
    Si4707 Breakout -------------- Arduino
      3.3V  ----------------------  3.3V
      GND   ----------------------  GND
      SDIO  ----------------------  SDA (A4 on older 'duinos)
      SCLK  ----------------------  SCL (A5 on older 'duinos
      RST   ----------------------   4 (can be any digital pin)

  Any other pins on the Si4707 breakout can be left unconnected.
  The SEN pin is pulled high, which will affect the I2C address.
  The GPO1/2 pins are not used as outputs, and their default
  states set the Si4707 into I2C mode.
  
  For more information on the Si4707, check out the abundance of
  information provided by Silicon Labs:
  https://www.silabs.com/products/audiovideo/amfmreceivers/Pages/Si4707.aspx
  Specifically, check out the Programming Guide (AN332).
   
  When you start up the sketch, it will attempt to initialize the
  Si4707 and tune to the frequency defined by the tuneFrequency
  global variable. After tuning a menu will be printed to the 
  serial monitor, have fun interacting with the options presented!
*/
#include "si4707_definitions.h"
#include <Wire.h>

// In 2-wire mode, connecting the SEN pin to the Arduino is optional.
//  If it's not connected, make sure SEN_ADDRESS is defined as 1
//  assuming SEN is pulled high as on the breakout board.
#define SEN_ADDRESS 1
// In two-wire mode: if SEN is pulled high
#if SEN_ADDRESS
  #define SI4707_ADDRESS 0b1100011
#else  // Else if SEN is pulled low
  #define SI4707_ADDRESS 0b0010001
#endif
  
// Pin definitions:
// (If desired, these pins can be moved to other digital pins)
// SEN is optional, if not used, make sure SEN_ADDRESS is 1
const int senPin = 5;  
const int rstPin = 4;
// Not defined, because they must be connected to A4 and A5, 
//  are SDIO and SCLK.

// Put the WB frequency you'd like to tune to here:
// The value should be in kHz, so 162475 equates to 162.475 MHz
// The sketch will attempt to tune to this frequency when it starts.
// Find your frequency here: http://www.nws.noaa.gov/nwr/indexnw.htm
unsigned long tuneFrequency = 162475; // 162.475 MHz

// Initial volume level:
int rxVolume = 63;  // Maximum loudness (should be between 0 and 63)

// The setup function initializes Serial, the Si4707, and tunes the Si4707
//  to the WB station defined at the top of this sketch (tuneFrequency).
//  To finish, it prints out the interaction menu over serial.
void setup()
{  
  // Serial is used to interact with the menu, and to print debug info
  Serial.begin(9600);
  
  // First, initSi4707() must be called. The function returns the value
  //  of the Part Number reported by the Si4707, which can be checked
  //  to verify communication. It should always be 7.
  byte partNumber = initSi4707();
  if (partNumber == 7)
    Serial.println("Successfully connected to Si4707");
  else
  {
    Serial.print("Didn't connect to an Si4707...Error: ");
    Serial.println(partNumber);
    while(1)
      ;
  }
  
  // After initializing, we can tune to a WB frequency. Use the
  //  setWBFrequency() function to tune to a frequency. The frequency 
  //  parameter given to the function should be your chosen frequency in
  //  kHz. So to tune to 162.55 MHz, send 162550. The tuneFrequency
  //  variable is defined globablly near the top of this sketch.
  if (setWBFrequency(tuneFrequency))
  {
    Serial.println(F("Tune Success!"));
  }
  else
    Serial.println(F("Tune unsuccessful"));
  
  // After tuning, check out the serial monitor to interact with the menu.
  printMenu();
}

void loop()
{
  // Wait for a serial byte to be received:
  while( !Serial.available() )
    ;
  char c = Serial.read();
  // Once received, act on the serial input:
  switch (c)
  {
  case 'u':
    tuneWBFrequency(1);  // Tune up 1 increment (2.5kHz)
    break;
  case 'd':
    tuneWBFrequency(-1);  // Tune down 1 increment (2.5kHz)
    break;
  case 'U':
    tuneWBFrequency(10);  // Tune up 10 increments (25kHz)
    break;
  case 'D':
    tuneWBFrequency(-10);  // Tune down 10 increments (25kHz)
    break;
  case 's':
    printSAMEStatus();
    break;
  case 'r':
    Serial.print("RSSI = ");
    Serial.println(getRSSI());
    break;
  case 'S':
    Serial.print("SNR = ");
    Serial.println(getSNR());
    break;
  case 'o':
    Serial.print("Frequency offset = ");
    Serial.println(getFreqOffset());
    break;
  case 'f':
    Serial.print("Frequency = ");
    // getWBFrequency() returns the 2-byte frequency code sent
    // to the Si4707. To get a real-looking freq, multiply by .0025
    Serial.print((float) getWBFrequency() * 0.0025, 4);
    Serial.println(" MHz");
    break;
  case 'm':
    setMuteVolume(1);  // Turn mute on
    break;
  case 'M':
    setMuteVolume(0);  // Turn mute off
    break;
  case '+':
    setVolume(++rxVolume); // increment volume
    break;
  case '-':
    setVolume(--rxVolume); // decrement volume
    break;
  case 'h':
    printMenu(); // print the help menu
  }
}

void printMenu()
{
  Serial.println();
  Serial.println(F("Si4707 Weather Band Example Code Menu"));
  Serial.println(F("====================================="));
  Serial.println(F("\t u) Fine tune up (+2.5kHz)"));
  Serial.println(F("\t d) Fine tune down (-2.5kHz)"));
  Serial.println(F("\t U) Coarse tune up (+25kHz)"));
  Serial.println(F("\t D) Coarse tune down (-25kHz)"));
  Serial.println(F("\t s) Get SAME status"));
  Serial.println(F("\t r) Get RSSI"));
  Serial.println(F("\t S) Get SNR"));
  Serial.println(F("\t o) Get Frequency offset"));  
  Serial.println(F("\t f) Get Tune Frequency"));
  Serial.println(F("\t m) Mute audio output"));
  Serial.println(F("\t M) Un-mute audio output"));
  Serial.println(F("\t +) Increase volume"));
  Serial.println(F("\t -) Decrease volume"));
  Serial.println(F("\t h) Re-print this menu"));
  Serial.println();
}

// initSi4707 performs the following functions, in sequence:
//  * Initialize all pins connected to Si4707 (SEN, SCLK, SDIO, and RST)
//  * Starts up the Wire class - used for two-wire communication
//  * Applies a reset signal to the Si4707
//  * Sends the Power Up command to the Si4707
//  * Sends the GET REV command to verify communication, returns the final
//    two digits of the Part Number (should be 7)
byte initSi4707()
{
  // Set initial pin value: RST (Active-low reset)
  pinMode(rstPin, OUTPUT);  // Reset
  digitalWrite(rstPin, LOW);  // Keep the SI4707 in reset
  
  // Set initial pin value: SEN (I2C Address select)
  pinMode(senPin, OUTPUT);  // Serial enable
  if (SEN_ADDRESS) 
    digitalWrite(senPin, HIGH);
  else 
    digitalWrite(senPin, LOW);
  
  // Set initial pin values: SDIO and SCLK (serial data and clock lines)
  // Wire.begin() will take care of this
  Wire.begin();
  delay(1);  // Short delay before we take reset up
  
  // Raise RST, SCLK must not rise within 300ns before RST rises
  digitalWrite(rstPin, HIGH);
  delay(1);  // Give Si4707 a little time to reset
  
  // First, send the POWER UP command to turn on the Si4707.
  // The Si4707 must be powered up before sending any further commands.
  powerUp();
  
  // See Si4707_system_functions.ino for info on command_Get_Rev
  return command_Get_Rev(1);    
}

// Ths function sets the Si4707 to the freq it receives.
// freq should represent the frequency desired in kHz.
// e.g. 162400 will tune the radio to 162.400 MHz.
byte setWBFrequency(long freq)
{
  // Keep tuned frequency between valid limits (162.4 - 162.55 MHz)
  long freqKhz = constrain(freq, 162400, 162550);;
    
  Serial.print("Tuning to: ");
  Serial.print((float) freqKhz / 1000.0, 4);
  Serial.println(" MHz");
  
  // See si4707_system_functions.ino for info on command_Tune_Freq
  return command_Tune_Freq((freqKhz * 10)/25);
}

// This function does incremental tunes on the Si4707. Send a
// signed value representing how many increments you'd like to go
// (up is positive, down is negative). Each increment is 2.5kHz.
void tuneWBFrequency(signed char increment)
{
  unsigned int freq = getWBFrequency();
  freq += increment;
  freq = constrain(freq, 64960, 65020);
    
  Serial.print("Tuning to: ");
  Serial.print((float) freq * 0.0025, 4);
  Serial.println(" MHz");
  
  // See si4707_system_functions.ino for info on command_Tune_Freq
  command_Tune_Freq(freq);
}

// Returns the two-byte Si4707 representation of the frequency.
unsigned int getWBFrequency()
{
  // See si4707_system_functions.ino for info on command_Tune_Status
  return command_Tune_Status(0, 2);
}

// Returns the recieved signal strength reported by Si4707
byte getRSSI()
{
  // See si4707_system_functions.ino for info on command_RSQ_Status
  return command_RSQ_Status(4);
}

// Returns the signal-to-noise ratio reported by the Si4707
byte getSNR()
{
  // See si4707_system_functions.ino for info on command_RSQ_Status
  return command_RSQ_Status(5);
}

// Returns the frequency offset reported by the Si4707
signed char getFreqOffset()
{
  // See si4707_system_functions.ino for info on command_RSQ_Status
  return (signed char) command_RSQ_Status(7);
}

// Prints the status value of the SAME status command
// Work still do be done on this function. (Haven't had a WSW recently!)
void printSAMEStatus()
{
  byte sameStatus = command_SAME_Status(2);
  if (!sameStatus)
    Serial.println("No SAME message detected");
  else
  {
    Serial.print("SAME status: ");
    Serial.println(sameStatus);
    Serial.print("Message length: ");
    Serial.println(command_SAME_Status(3));
  }
}

// Depending on the value of the mute boolean, this function will either
//  mute (mute=1) or un-mute (mute=0) the Si4707's audio output.
void setMuteVolume(boolean mute)
{
  // Mute left (bit 1) and right (bit 0) channels
  setProperty(PROPERTY_RX_HARD_MUTE, (mute<<1) | (mute<<0));
}

// This functionn interacts with the RX_VOLUME property of the Si4707.
//  Send a volume value (vol) between 0 (mute) and 63 (max volume).
void setVolume(int vol)
{
  vol = constrain(vol, 0, 63); // vol should be between 0 and 63 
  setProperty(PROPERTY_RX_VOLUME, vol);
}

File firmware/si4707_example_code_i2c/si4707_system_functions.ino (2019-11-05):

/* Si4707_system_functions contains the nitty gritty system
   functions used to interface with the Si4707. High-level stuff,
   like constructing command strings, and parsing response strings.
   Also functions like sending commands, and waiting for the
   clear-to-send bit to be set.

   There are prettier wrappers for most of these functions in
   the example sketch.

   At the bottom of this sketch are functions used to interface
   with the Wire library - i2cWriteBytes and i2cReadBytes. */

//////////////////////////////
// High level functions //////
//////////////////////////////

// These arrays will be used by most command functions to construct
// the command string and receive response bytes.
byte rsp[15];
byte cmd[8];

/* powerup(): Sends the POWER_UP command to initiate the boot
   process, moving the Si4707 from powerdown to powerup mode.

   This performs critical operations in configuring the Si4707
   crystal oscillator, and turning on WB receive. */
void powerUp(void)
{
  /* Power up (0x01) - initiate boot process.
     2 Arguments:
       ARG1: (CTSIEN)(GPO2OEN)(PATCH)(XOSCEN)(FUNC[3:0])
       ARG2: (OPMODE[7:0])
     Response: none (if FUNC = 3)*/
  cmd[0] = COMMAND_POWER_UP;  // Command 0x01: Power Up
  cmd[1] = 0x53;  // GP02 output enabled, crystal osc enabled, WB receive mode
  cmd[2] = 0x05;  // Use analog audio outputs
  writeCommand(3, cmd, 0, rsp);

  delay(POWER_UP_TIME_MS);
}

/* command_Tune_Freq(uint16_t frequency) sends the WB_TUNE_FREQ command
  with freqeuncy as the arguments. After tuning, the WB_TUNE_STATUS
  command is sent to verify whether or not tuning was succesful.

  frequency should be a 16-bit value equal to the freq. you want to
  tune to divided by 2.5kHz.
  For example, for 162.4MHz send 64960 (162400000 / 2500 = 64960)
  For 162.55 MHz send 65020 (162550000 / 2500 = 65020).

  Return RESP1 byte of WB_TUNE_STATUS response (valid and afcrl bits) */
byte command_Tune_Freq(unsigned int frequency)
{
  cmd[0] = COMMAND_WB_TUNE_FREQ;
  cmd[1] = 0;
  cmd[2] = (uint8_t)(frequency >> 8);
  cmd[3] = (uint8_t)(frequency & 0x00FF);
  writeCommand(4, cmd, 1, rsp);

  delay(500); // Delay required to allow time to tune

  return (command_Tune_Status(1, 1) >> 8);
}

/* WB_TUNE_STATUS (0x52) - Returns current frequency and RSSI/SNR
  at the moment of tune.
   Arguments (1 byte):
     (1) ARG1 - bit 0: INTACK (if set, clears seek/tune complete int)
   Response (6 bytes):
     (1) Status
     (2) bit 1: AFC rail indicator
         bit 0: Valid channel indicator
     (3) READFREQ(H) - Read frequency high byte
     (4) READFREQ(L) - Read frequency low byte
     (5) RSSI - Receive signal strength at frequency
     (6) SNR - Signal-to-noise ratio at frequency */
unsigned int command_Tune_Status(byte intAck, byte returnIndex)
{
  cmd[0] = COMMAND_WB_TUNE_STATUS;
  cmd[1] = (intAck & 0x01);
  writeCommand(2, cmd, 6, rsp);

  return ((rsp[returnIndex] << 8) | rsp[returnIndex + 1]);
}

/* command_Get_Rev() sends the GET_REV command
   Response (9 bytes):
     (0) Status (Should have CTS bit (7) set)
     (1) PN[7:0] - Final two digits of part number
     (2) FWMAJOR[7:0] - Firmware major revision
     (3) FWMINOR[7:0] - Firmware minor revision
     (4) PATCH(H) - Patch ID high byte
     (5) PATCH(L) - Patch ID low byte
     (6) CMPMAJOR[7:0] - Component major revision
     (7) CMPMINOR[7:0] - Component minor revision
     (8) CHIPREV[7:0] - Chip revision

   Returns the response byte requested */
byte command_Get_Rev(byte returnIndex)
{
  cmd[0] = COMMAND_GET_REV;
  writeCommand(1, cmd, 9, rsp);

  return rsp[returnIndex];
}
/* command_SAME_Status() sends the WB_SAME_STATUS command and
  returns the requested byte in the response

  Arguments (2 bytes):
    (0): ()()()()()()(CLRBUF)(INTACK)
    (1): READADDR[7:0]
   Response (13 bytes):
    (0): Status byte
    (1): ()()()()(EMODET)(SOMDET)(PREDET)(HDRRDY)
    (2): STATE[7:0]
    (3): MSGLEN[7:0]
    (4): Confidence of data bytes 7-4
    (5): Confidence of data bytes 3-0
    (6-13): DATA0, DATA1, ..., DATA7

  This fucntion needs some work... */
byte command_SAME_Status(byte returnIndex)
{
  cmd[0] = COMMAND_WB_SAME_STATUS;
  cmd[1] = 0;
  cmd[2] = 0;

  writeCommand(3, cmd, 14, rsp);

  return rsp[returnIndex];
}
/* WB_RSQ_STATUS (0x53) - Returns status information about
  received signal quality - RSSI, SNR, freq offset.
   Argument (1 byte):
     (0) bit 0: Interrupt acknowledge
   Response (8 bytes):
     (0) Status (Should have CTS bit (7) set)
     (1) RESP1: ()()()()(SNRHINT)(SNRLINT)(RSSIHINT)(RSSILINT)
     (2) RESP2: ()()()()()()(AFCRL)(VALID)
     (3) Nothing
     (4) RSSI[7:0] - Received signal strength indicator
     (5) SNR[7:0] - Signal-to-noise metric
     (6) Nothing
     (7) FREQOFF[7:0] - signed frequency offset in kHz  */
byte command_RSQ_Status(byte returnIndex)
{

  cmd[0] = COMMAND_WB_RSQ_STATUS;
  cmd[1] = 0;

  writeCommand(2, cmd, 8, rsp);

  return rsp[returnIndex];
}

/* command_Get_Int_Status() sends the GET_INT_STATUS command and returns
  the byte from the commands response
*/
byte command_Get_Int_Status(void)
{
  cmd[0] = COMMAND_GET_INT_STATUS;
  cmd[1] = 0;
  rsp[1] = 0;

  writeCommand(1, cmd, 1, rsp);

  return rsp[0];
}

// This function will wait until the CTS (clear-to-send) bit has
// been set (or will timeout after 500 ms)
void waitForCTS(void)
{
  byte status = 0;
  int i = 1000;

  while (--i && !(status&0x80))
  {
    i2cReadBytes(1, &status);
    delayMicroseconds(500);
  }
}

// This function will write a command string with a given size
// And retrun a filled reply string with replySize bytes in it.
void writeCommand(byte cmdSize, byte * command, byte replySize, byte * reply)
{
  waitForCTS();
  i2cWriteBytes(cmdSize, command);
  waitForCTS();
  if (replySize)
  {
    i2cReadBytes(replySize, reply);
  }

  for (int i=0; i<replySize; i++)
  {
    reply[i] += 1;
    reply[i] -= 1;
  }
}

// This function returns a two-byte property from the requested
// property address.
unsigned int getProperty(unsigned int property)
{
  cmd[0] = COMMAND_GET_PROPERTY;
  cmd[1] = 0;
  cmd[2] = (byte)((property & 0xFF00) >> 8);
  cmd[3] = (byte)(property & 0x00FF);
  writeCommand(4, cmd, 4, rsp);

  return ((rsp[2] << 8) | rsp[3]);
}

// This function sets a property to the given two-byte property
//  value.
void setProperty(unsigned int propNumber, unsigned int propValue)
{
  cmd[0] = COMMAND_SET_PROPERTY;
  cmd[1] = 0;
  cmd[2] = (uint8_t)(propNumber >> 8);
  cmd[3] = (uint8_t)(propNumber & 0x00FF);
  cmd[4] = (uint8_t)(propValue >> 8);
  cmd[5] = (uint8_t)(propValue & 0x00FF);

  writeCommand(6, cmd, 1, rsp);
}

//////////////////////////////
// Low level functions ///////
//////////////////////////////
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

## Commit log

2013-01-14 Hardware files - v11
    Also adding readme files.
    [Si4707-Breakout.brd, Si4707-Breakout.sch]
2013-01-14 Adding bStop to solder jumper.
    Much easier to cut jumpers when they're exposed!
    [Si4707-Breakout.brd]
2013-01-15 Production readied
    Added fiducials to design. Created production panel.
    [Si4707-Breakout-Panel-v11.brd, Si4707-Breakout.brd, Si4707-Breakout.sch]
2013-03-01 Adding working I2C example code
2013-03-04 Few minor comment fixes
    [si4707_example_code_i2c.ino]
2013-03-20 Cleaning up schematic, matching it up to release
    [Si4707-Breakout.brd, Si4707-Breakout.sch]
2015-05-12 Updating directory structure, adding version to hardware files, updating readme
    [Si4707-Breakout-Panel-v11.brd, SparkFun_Si4707_Breakout.brd, SparkFun_Si4707_Breakout.sch]
2019-11-05 Update si4707_system_functions.ino
    Removing unnecessary Wire.endTransmission().

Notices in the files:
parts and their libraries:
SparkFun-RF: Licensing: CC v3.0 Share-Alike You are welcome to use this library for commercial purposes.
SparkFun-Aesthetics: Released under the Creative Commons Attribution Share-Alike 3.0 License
